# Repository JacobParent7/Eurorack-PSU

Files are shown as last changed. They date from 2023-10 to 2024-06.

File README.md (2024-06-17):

# Eurorack-PSU
This repository has the KiCAD design files for a simple +12/-12V Eurorack PSU PCB. It also includes the BOM, CPL, and compressed GERBER files to order directly from a PCB Fab.

## Schematic Design



## Footprint Design



## Design Description
This design utilizes a wall wart AC/AC converter which provides a ~17Vpp AC signal to the board. The board then rectifies this signal into its positive and negative parts and filters the rectified signals to a max ripple of 1V for the inputs of both regulators. This filtered signal is sent to two voltage regulators which have high frequency tantalum compensation capacitors. These regulators directly provide the -12/+12V rails. The LM7812 does not have a built in protection diode so that is why it's included.



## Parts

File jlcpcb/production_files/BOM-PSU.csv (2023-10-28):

Comment | Designator | Footprint | LCSC
L7912 | U2 | TO-220F-3_Vertical | C163542
L7812 | LM7812 | TO-220F-3_Vertical | C29119
2000uF | C5,C6 | CP_Radial_D10.0mm_P5.00mm | C442838
4700uf | C1,C2,C3,C4 | CP_Radial_D16.0mm_P7.50mm | C45070
1N4007 | D1,D2,D3 | D_DO-41_SOD81_P10.16mm_Horizontal | C483896
1uF | C10,C7,C8,C9 | CP_EIA-3528-21_Kemet-B | C600504

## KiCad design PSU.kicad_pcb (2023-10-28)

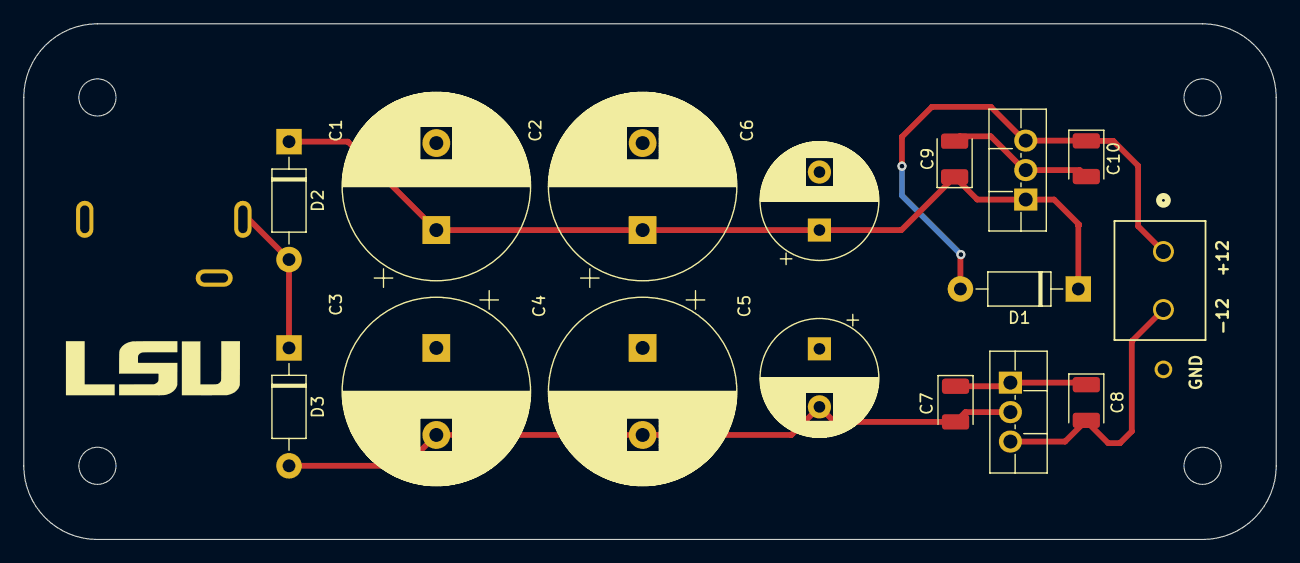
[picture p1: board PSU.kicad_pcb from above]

Board: 2 copper layers, 107.9 x 44.5 mm, 21 parts (0 on the bottom side), 6 nets.

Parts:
C1, C2, C3: 4700uf; CP_Radial_D16.0mm_P7.50mm
C4: 4700uF; CP_Radial_D16.0mm_P7.50mm
C5, C6: 2000uF; CP_Radial_D10.0mm_P5.00mm
C7, C8, C9, C10: 1uF; CP_EIA-3528-21_Kemet-B
D1, D2, D3: 1N4007; D_DO-41_SOD81_P10.16mm_Horizontal
H1, H2, H3, H4: MountingHole; MountingHole_3.2mm_M3
J1: MJ-3536NG; MJ-3536NG_CUD
J2: 691137710002; CONN2_710002_WRE
LM7812: L7812; TO-220F-3_Vertical
U2: L7912; TO-220F-3_Vertical

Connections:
+12V: C10.1, D1.2 (A), J2.1, LM7812.3 (OUT)
-12V: C8.2, J2.2, U2.3 (VO)
GND: C1.2, C2.2, C3.1, C4.1, C5.1, C6.2, C7.1, C8.1, C9.2, C10.2, J1.6, J2.3, LM7812.2 (GND), U2.1 (GND)
unnamed: C1.1, C2.1, C6.1, C9.1, D1.1 (K), D2.1 (K), LM7812.1 (IN)
unnamed: D2.2 (A), D3.1 (K), J1.6
unnamed: C3.2, C4.2, C5.2, C7.2, D3.2 (A), U2.2 (VI)

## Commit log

2023-10-28 PCB Design and FAB files
    [BOM-PSU.csv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]
2023-11-13 Update README.md
    Boards came in
